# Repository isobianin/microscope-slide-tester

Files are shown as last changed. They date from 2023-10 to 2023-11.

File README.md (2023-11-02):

# Microscope slide tester

This is a small project done in collaboration with [Igor Kraev](https://uk.linkedin.com/in/igor-kraev-78a55821) from the Open University Microscope Suite. The device at hand is a simple continuity tester which is equipped with
a battery holder and can be recharged.

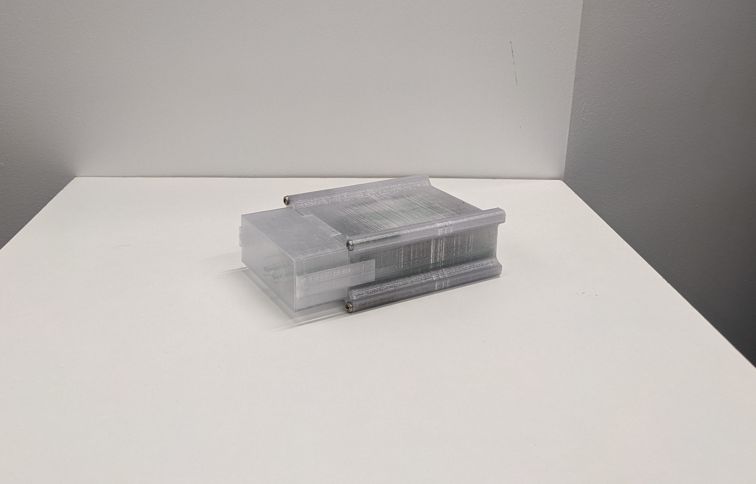
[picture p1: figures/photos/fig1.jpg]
 
 
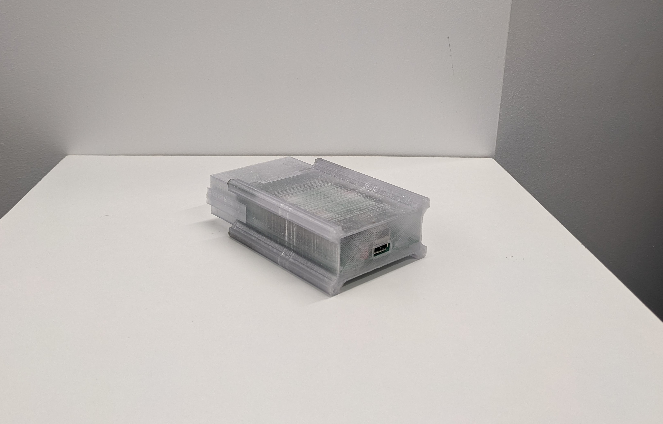
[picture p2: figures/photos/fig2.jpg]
 

The protocol of operation:

1. Take the electrode lid off.

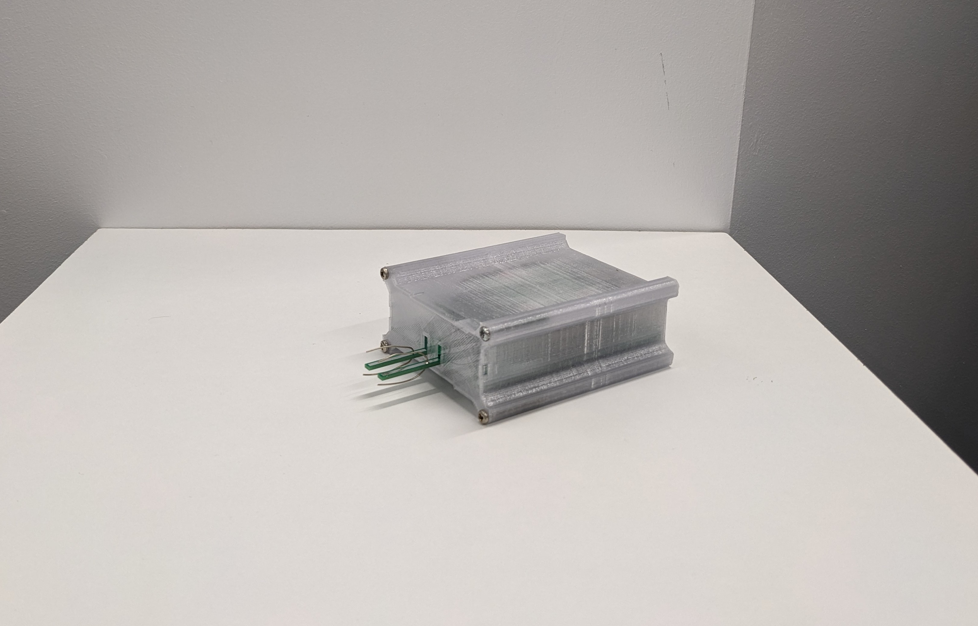
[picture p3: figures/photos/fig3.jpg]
lid-off
 

2. Clean your electrodes with either distilled water, acetone or IPA to remove any dust particles.

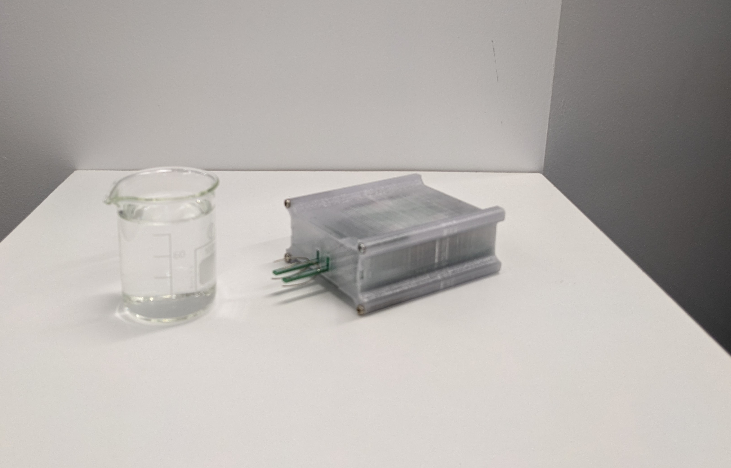
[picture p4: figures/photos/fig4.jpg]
solution
 

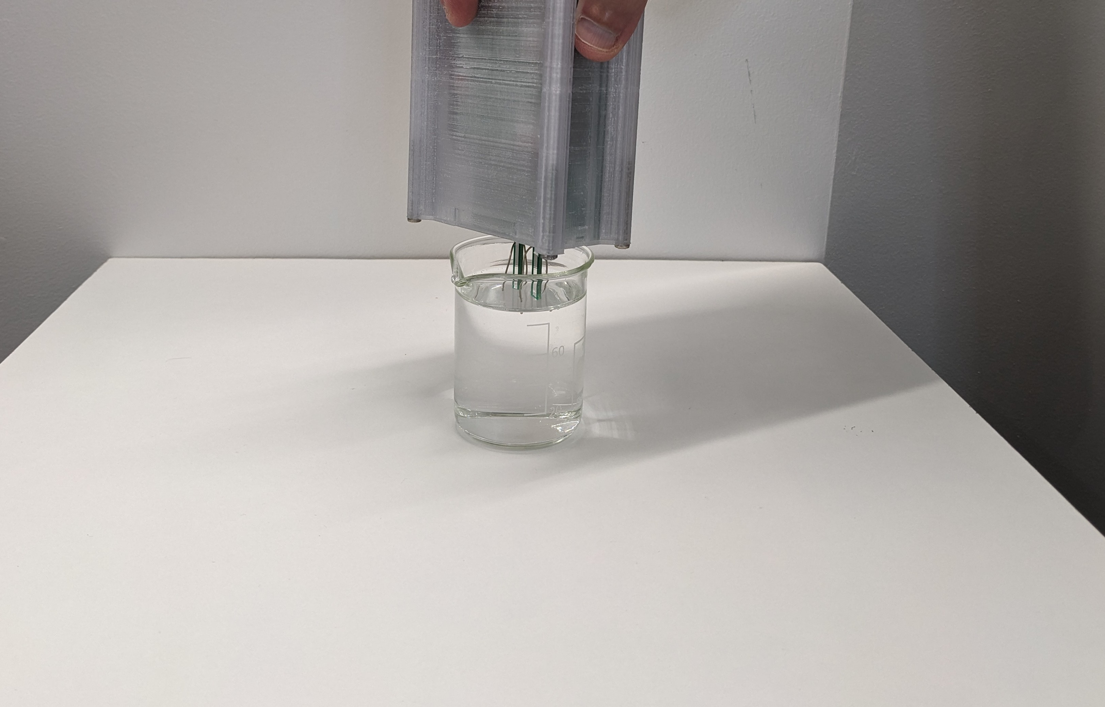
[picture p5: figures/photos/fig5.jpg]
cleaning
 

3. Press the slide against the electrodes. **If the front LED lights up, the side that is in contact with electrodes is conductive**.

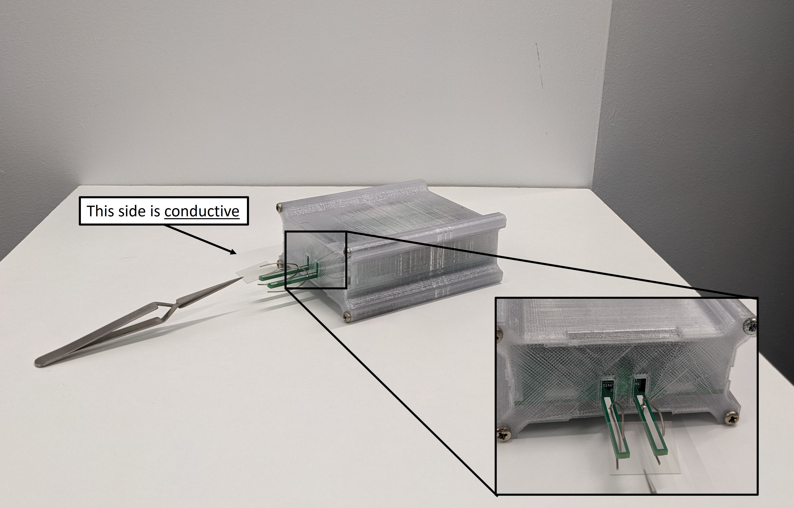
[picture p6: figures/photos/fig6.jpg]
non-conductive
 
 
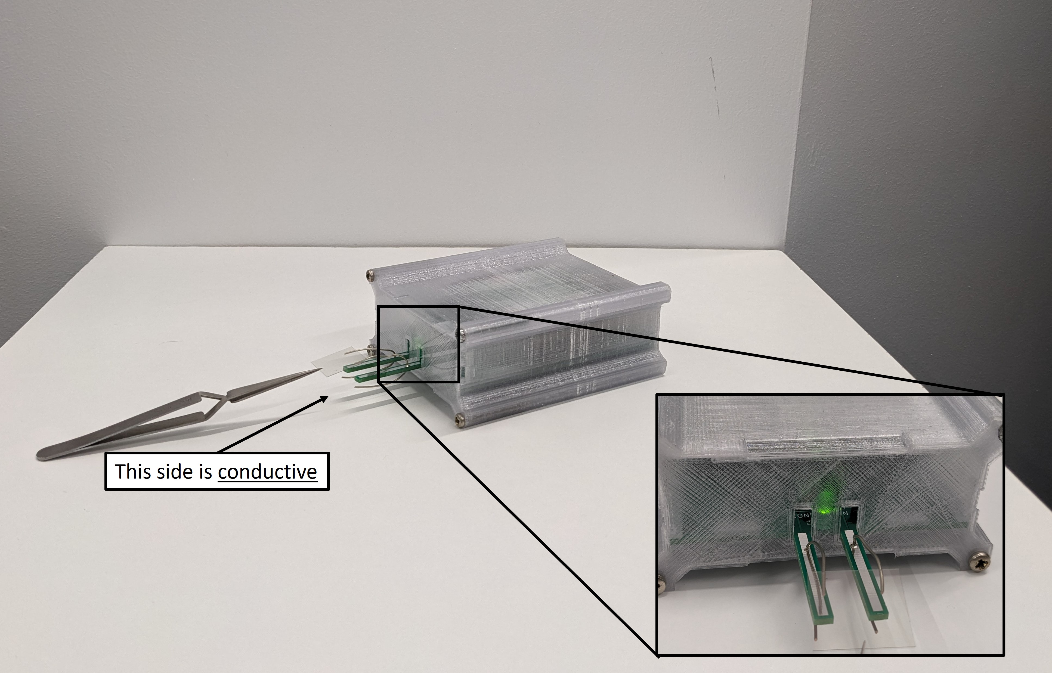
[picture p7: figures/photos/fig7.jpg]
conductive
 

4. Mark the conductive side.

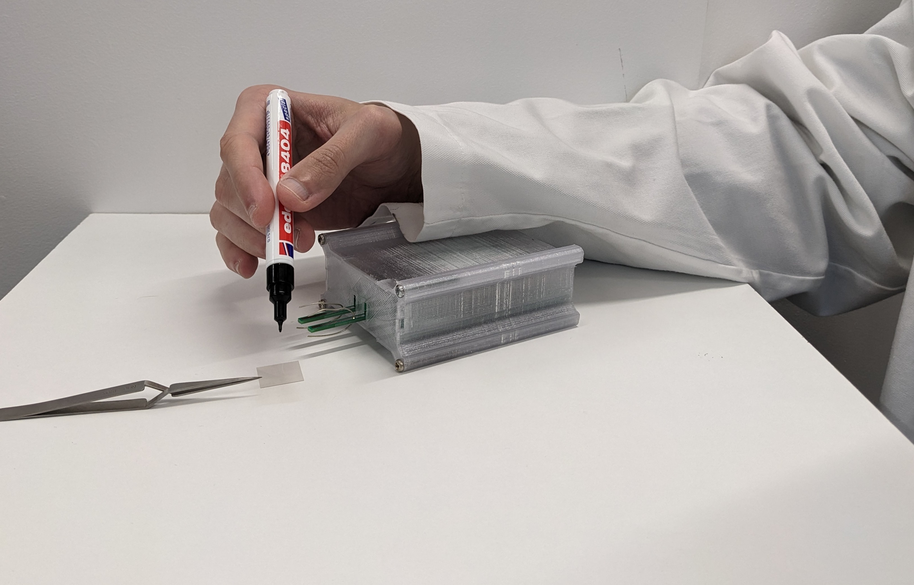
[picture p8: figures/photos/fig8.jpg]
marking
 

5. Repeat steps 1-4 for as many slides as needed.

6. When done, close the electrode lid.

 lid-on

The tester can be operated while being charged

# Recharging and safety

The tester can be recharged from any USB port (5V). That includes a PC, a laptop or even a phone charger. In the baseline version, USB B is installed at the back of the teste. It
can be swapped for any other convenient connector. USB A to USB B is a quite common cable and can be found in lots of printers, scanners, in electronic workshops, etc.

There are no specific regulations for the battery charging. When the tester is being charged, an indicator in the back lights up. A so-called **"trickle charge"** technique is used to 
charge the batteries. It means that the duration of charging is extremely long (tens of hours) but you cannot overcharge the batteries. 

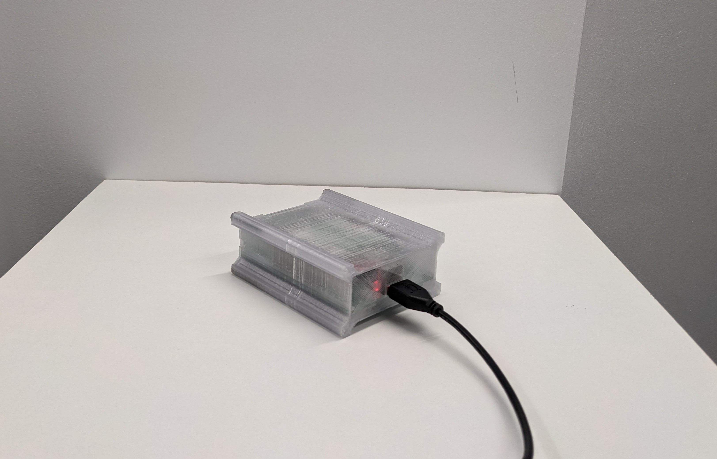
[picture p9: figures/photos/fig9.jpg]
recharging
 

A suggested protocol of recharging is to charge the device while you are at your workplace and avoid leaving it charging for days and days for safety measures.

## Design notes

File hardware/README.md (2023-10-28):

# Printed circuit boards

There are two available printed circuit board (PCB) designs. One features two plated through holes (PTH) which need to be soldered with a copper wire to create electrodes. This PCB is easier in manufacturing and handling.

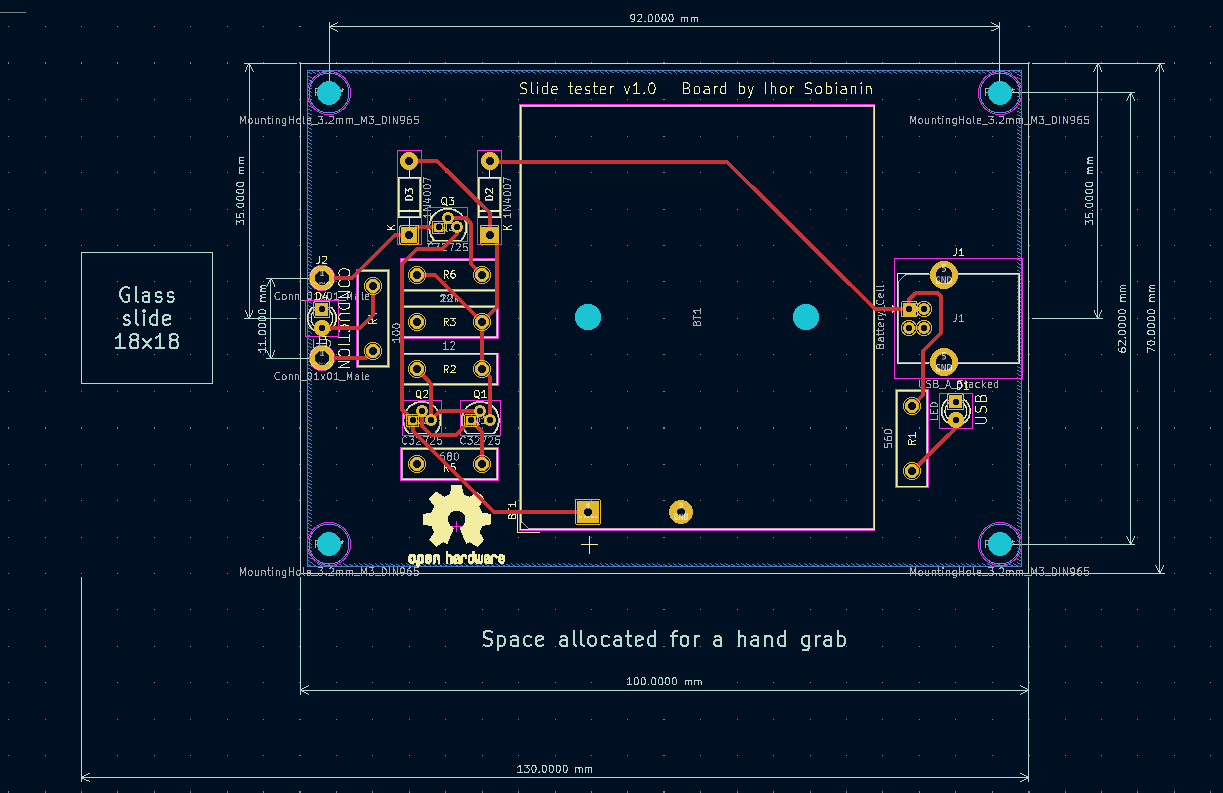
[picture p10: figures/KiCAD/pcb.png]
 

The other PCB design features two dedicated electrodes. The issue with this design, which is the original design, is that you need to explicitly specify to the manufacturer that these electrodes must cover
the whole area without any solder mask left on electrode pads. Otherwise, the solder mask is going to be taller than electrodes and a slide might not be able to touch the pads. Yet, this version also has PTH as a back-up.

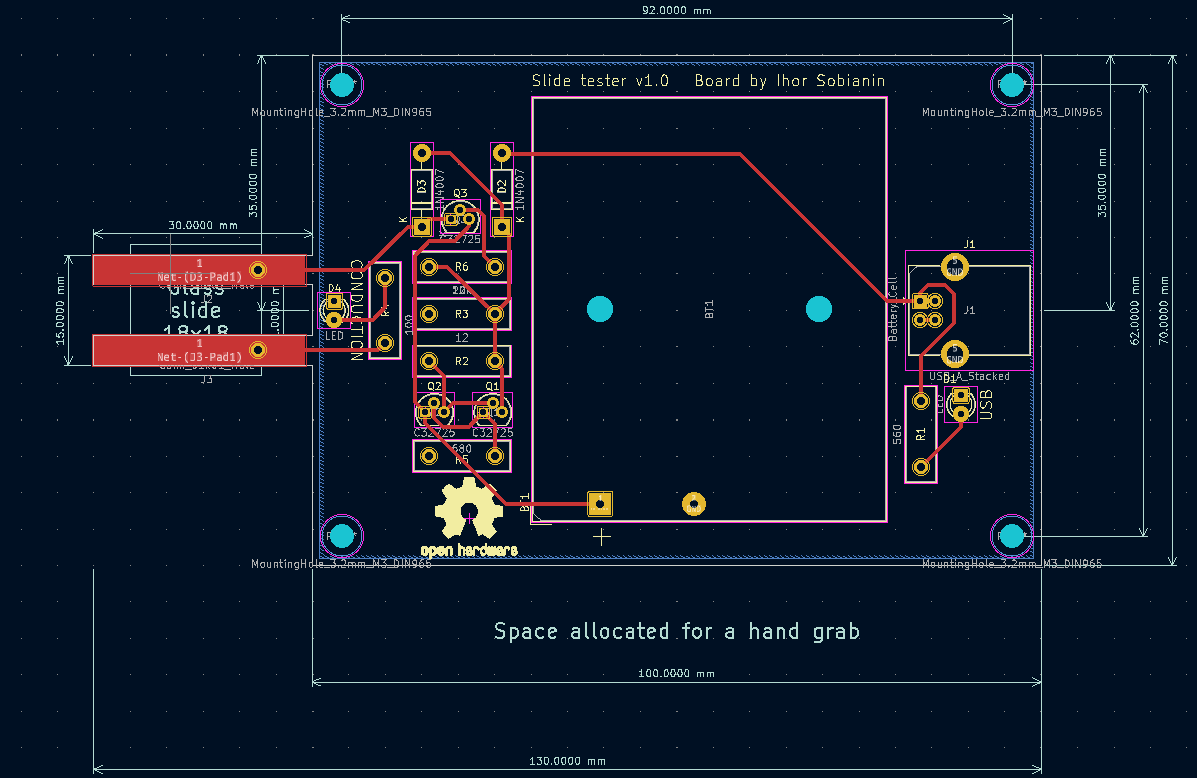
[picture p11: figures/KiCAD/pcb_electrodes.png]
 

Both use USB B connector for charging but feel free to swap those for whatever suits you.

# Bill of Materials

Components used:

Resistors

- 12 $\Omega$
- 100 $\Omega$
- 560 $\Omega$
- 680 $\Omega$
- 10k $\Omega$
- 22k $\Omega$

Diodes

- 2x 1n4007

LEDs

- 5 mm Green LED
- 5 mm Red LED

Transistors

- 3x C32725

Miscellaneous

- USB B connector
- 3x AA batteries
- 3x AA battery holder
- USB A to USB B cable

# Cicruitry

From the perpective of circuit design, the modus operandi is simple. When USB is connected, it set up the current mirror. Resistor R2 value is picked up to allow about 50 mA to pass through the Q2 transistor
into the batteries thus charging them. In the same time, Q3 acts as a switch and restricts current from flowing from the batteries while USB is connected and the tested D4 LED lights up using energy only from
the connector. When USB is disconnected, Q3 conducts and batteries are used to test slides.

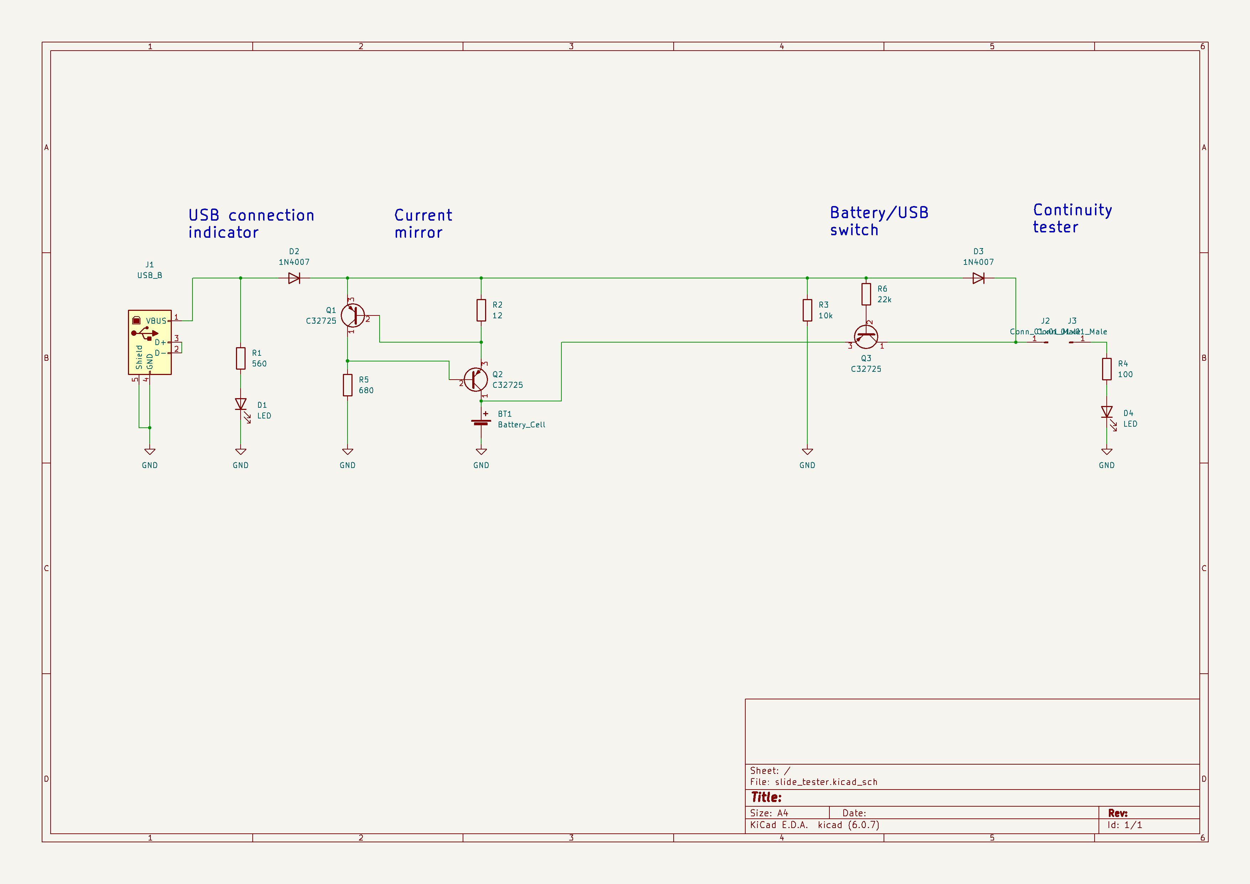
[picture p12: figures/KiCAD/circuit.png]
circuit
 

A highlight of this circuit is extensive use of C32725 transistors without use of any other components which makes it cheaper and more accessible.

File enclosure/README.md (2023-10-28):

# Enclosure

 The enclosure consists of 3 parts:
 
 1. base
 
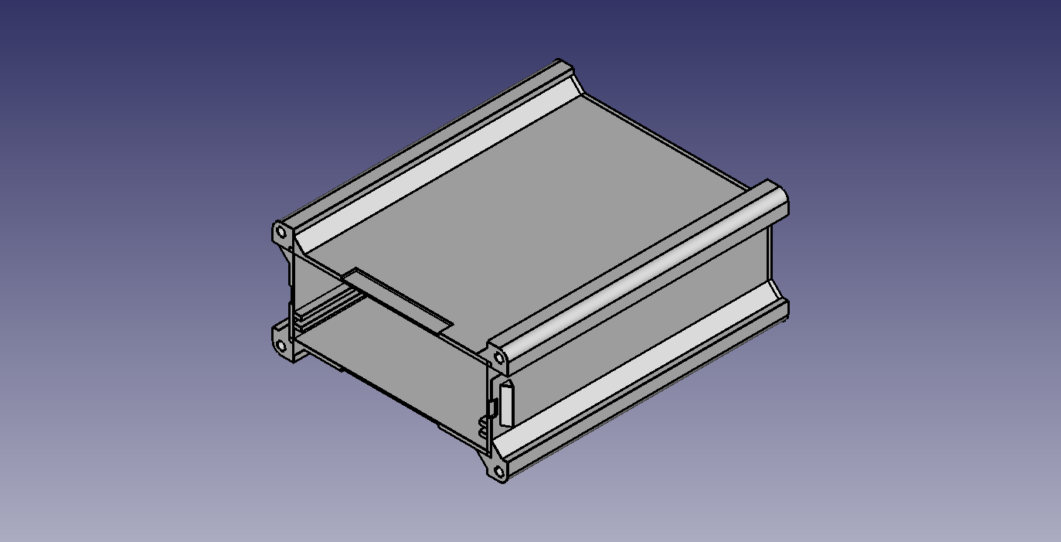
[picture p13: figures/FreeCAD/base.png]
base
 
 
 2. mechanical lid
 
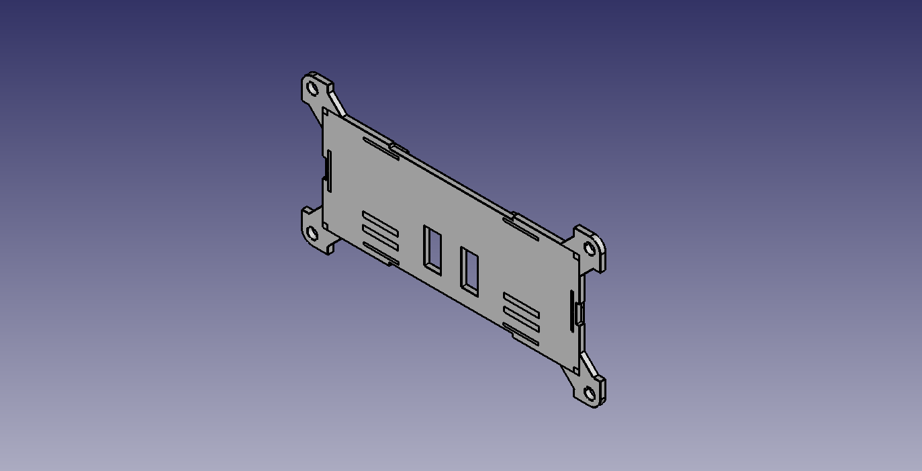
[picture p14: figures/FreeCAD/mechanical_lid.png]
mechanical lid
  
 
 3. electrode lid
 
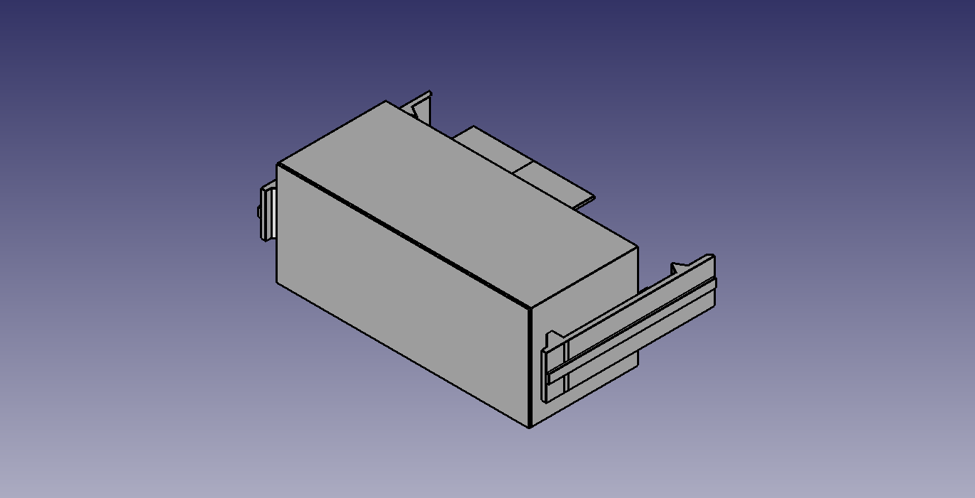
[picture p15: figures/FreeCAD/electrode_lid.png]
electrode lid
  
 
 They all can be 3D printed and barely require support material, if any. 
 
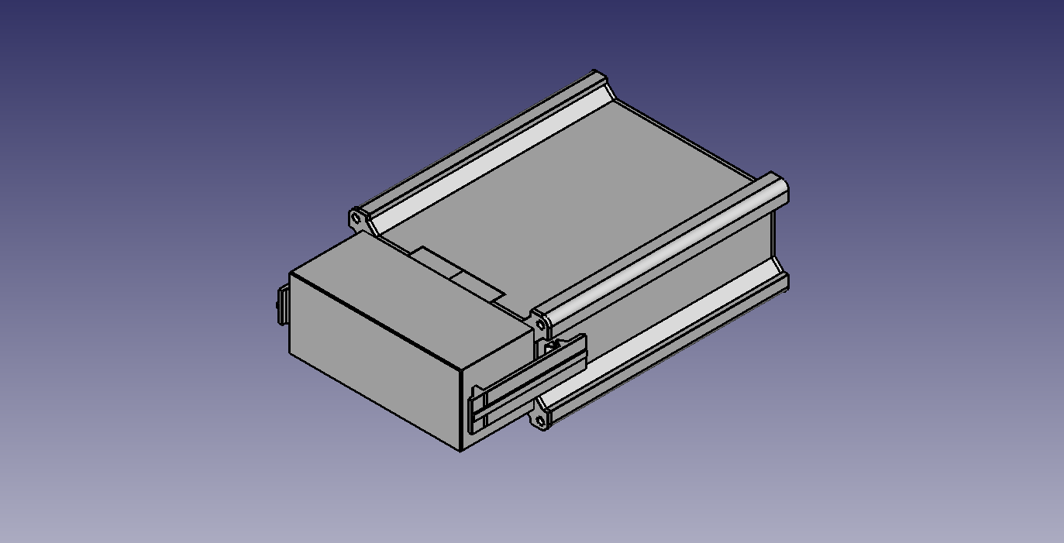
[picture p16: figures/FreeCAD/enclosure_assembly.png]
enclosure assembly
 
 
 # Parameters
 
 The FreeCAD file comes in a fully parametrised package. In the file you can find "Parameters" spreadsheet which contains almost all the desired geometrical dependencies.
 Thus, it is possible to customise the enclosure for your specific use. Moreover, it is relatively easy to limit the enclosure to the use of just two parts: the base and either one of lids.
 
 Most importantly, it is possible to vary the thickness and tolerances (both mechanical tolerances of the PCB and the 3D printer)
 
 # Fabrication
 
 Ultimaker S5 with UltraFuse transparent PET were used to fabricate the prototype. LEDs should still be visible even if the enclosure is printed with opaque filament. The front LED has enough space
 for it and the charging LED should still be visible through small gaps near the USB connector and the back of the enclosure.

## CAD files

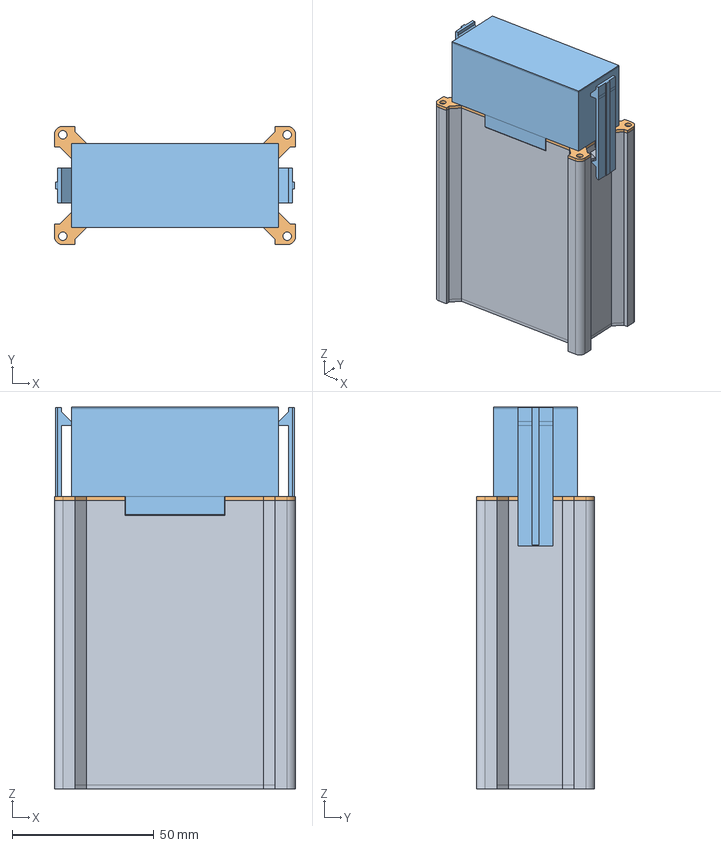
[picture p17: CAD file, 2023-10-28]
enclosure/uscope_slide_enclosure.FCStd
85.2 x 41.8 x 134.8 mm
EnclosureBase
MechanicalLid
ElectrodeLid

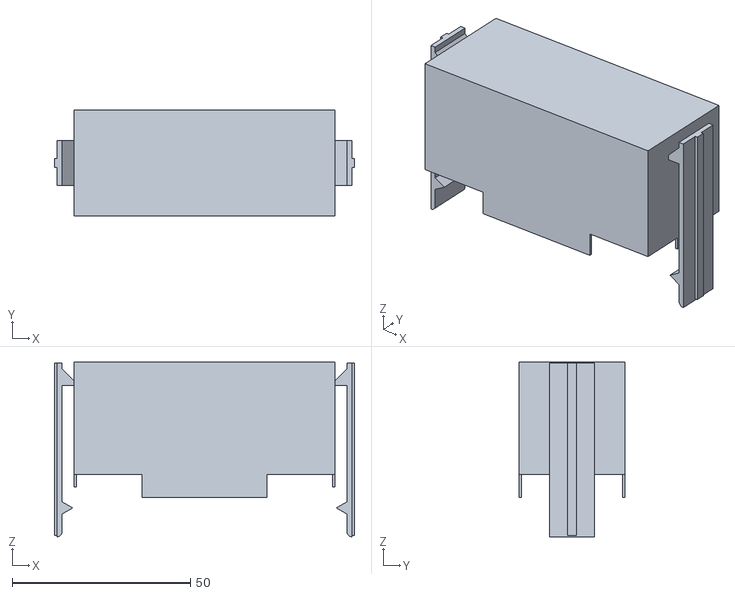
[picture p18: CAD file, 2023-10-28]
enclosure/uscope_slide_enclosure-ElectrodeLid.stl
84.2 x 29.8 x 49.1

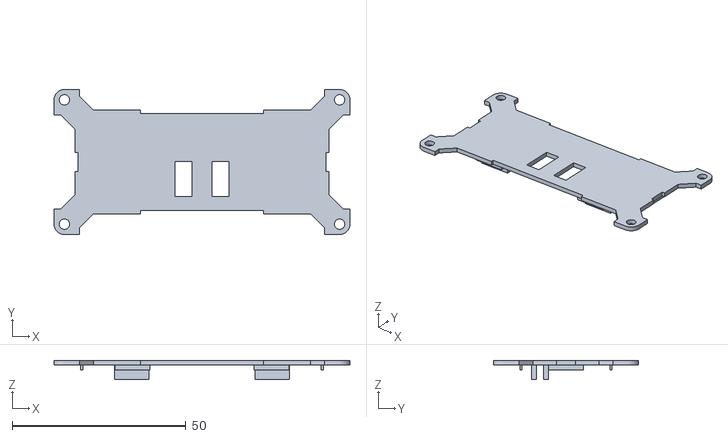
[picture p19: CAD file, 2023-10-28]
enclosure/uscope_slide_enclosure-MechanicalLid.stl
85.2 x 41.8 x 5.60

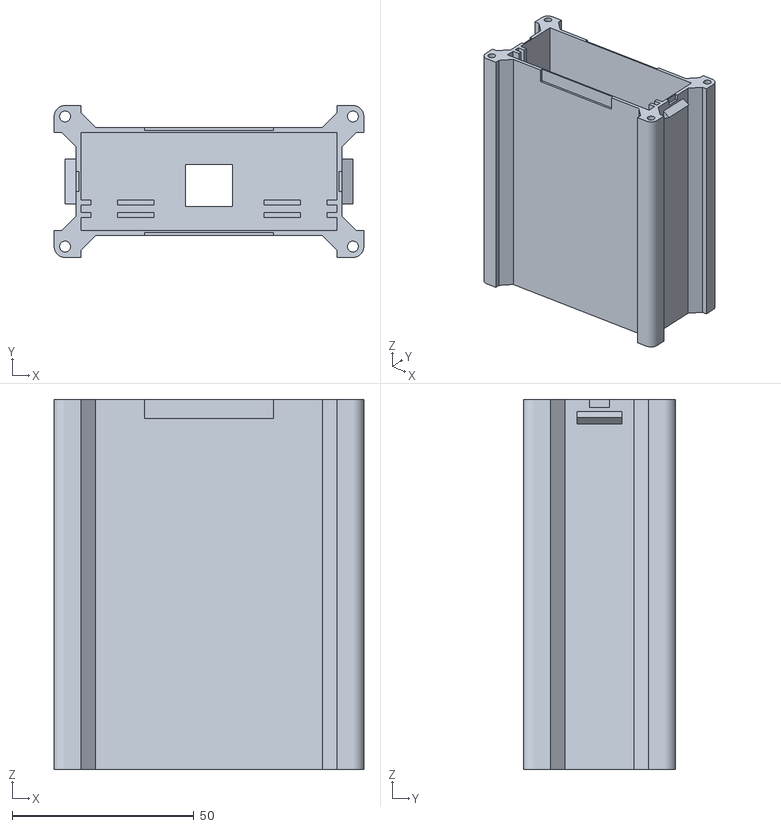
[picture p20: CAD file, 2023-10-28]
enclosure/uscope_slide_enclosure-EnclosureBase.stl
85.2 x 41.8 x 101.8

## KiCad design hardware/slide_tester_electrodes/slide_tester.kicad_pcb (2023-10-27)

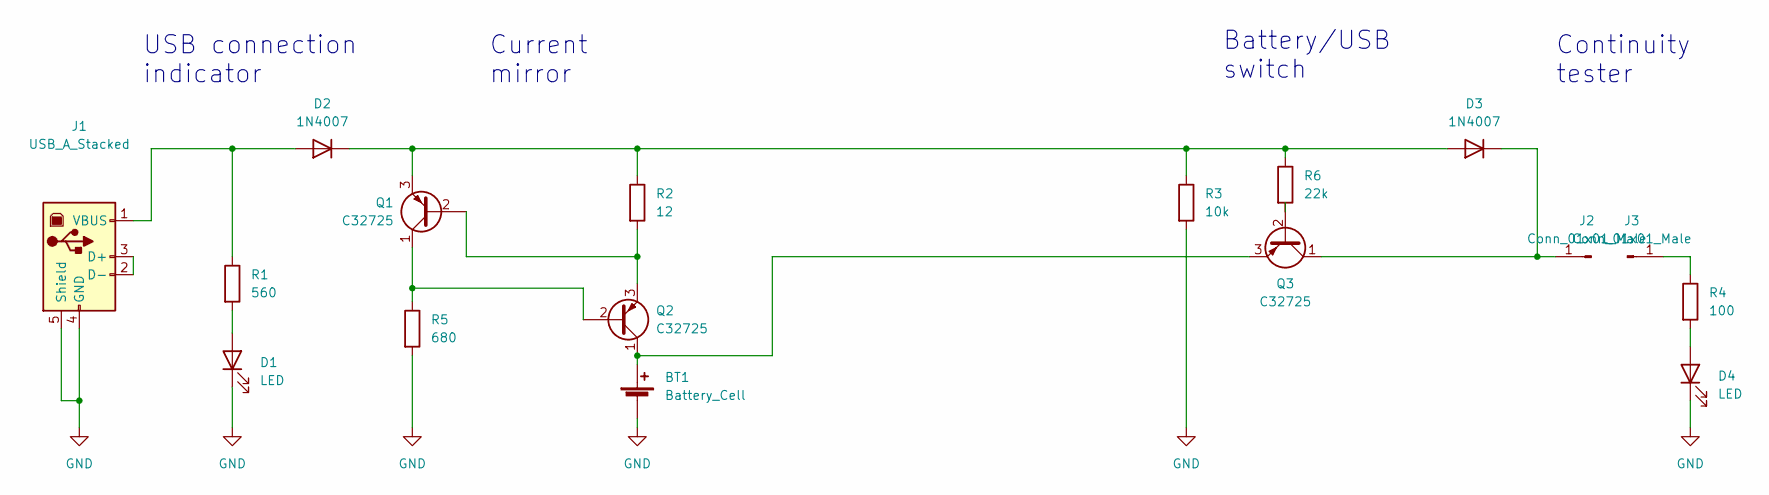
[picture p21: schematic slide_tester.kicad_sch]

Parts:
BT1: Battery_Cell; BatteryHolder_TruPower_BH-331P_3xAA
D1, D4: LED; LED_D3.0mm
D2, D3: 1N4007; D_DO-41_SOD81_P10.16mm_Horizontal
J1: USB_A_Stacked; USB_B_OST_USB-B1HSxx_Horizontal
J2, J3: Conn_01x01_Male; electrode_pad
Q1, Q2, Q3: C32725; TO-92
R1: 560; R_Box_L13.0mm_W4.0mm_P9.00mm
R2: 12; R_Box_L13.0mm_W4.0mm_P9.00mm
R3: 10k; R_Box_L13.0mm_W4.0mm_P9.00mm
R4: 100; R_Box_L13.0mm_W4.0mm_P9.00mm
R5: 680; R_Box_L13.0mm_W4.0mm_P9.00mm
R6: 22k; R_Box_L13.0mm_W4.0mm_P9.00mm

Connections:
GND: BT1.2 (-), D1.1 (K), D4.1 (K), J1.4 (GND), J1.5 (Shield), R3.2, R5.2
unnamed: BT1.1 (+), Q2.1 (C), Q3.3 (E)
unnamed: D1.2 (A), R1.2
unnamed: D2.1 (K), D3.2 (A), Q1.3 (E), R2.1, R3.1, R6.1
unnamed: D2.2 (A), J1.1 (VBUS), R1.1
unnamed: D3.1 (K), J2.1, Q3.1 (C)
unnamed: D4.2 (A), R4.2
unnamed: J1.2 (D-), J1.3 (D+)
unnamed: J3.1, R4.1
unnamed: Q1.1 (C), Q2.2 (B), R5.1
unnamed: Q1.2 (B), Q2.3 (E), R2.2
unnamed: Q3.2 (B), R6.2

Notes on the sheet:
Current mirror
Continuity tester
Battery/USB switch
USB connection indicator

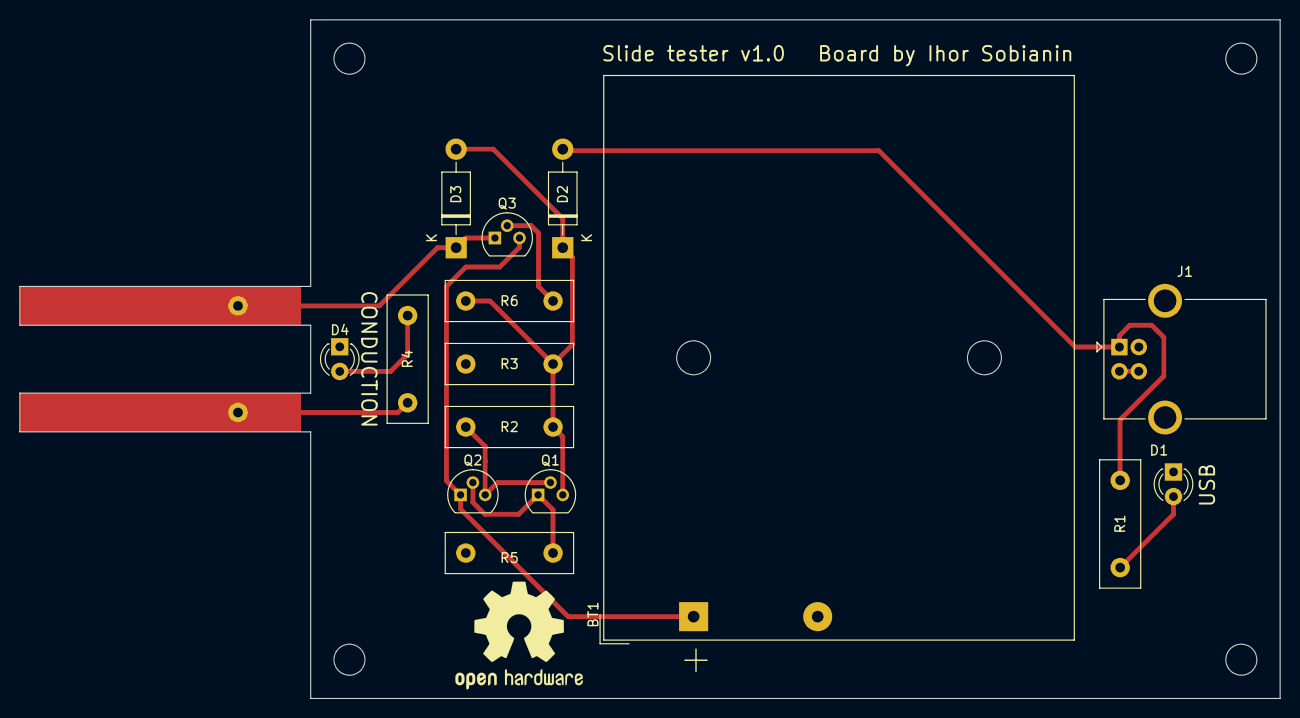
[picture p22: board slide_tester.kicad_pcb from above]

Board: 2 copper layers, 130.0 x 70.0 mm, 17 parts (0 on the bottom side), 12 nets.

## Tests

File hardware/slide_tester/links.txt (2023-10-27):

https://www.electroschematics.com/continuity-tester-differentiates-resistance/ - good design based on lm358
https://www.instructables.com/Modern-Continuity-Tester/
https://www.brighthubengineering.com/diy-electronics-devices/67224-build-yourself-a-simple-continuity-tester/

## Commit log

2023-10-27 Initial commit
    -create repo
    -add files
    [slide_tester-B_Cu.gbr, slide_tester-B_Mask.gbr, slide_tester-B_Paste.gbr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]
2023-10-27 Add enclosure
    Add FreeCAD enclosure files and STLs
    [uscope_slide_enclosure-ElectrodeLid.stl, uscope_slide_enclosure-EnclosureBase.stl, uscope_slide_enclosure-MechanicalLid.stl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]
2023-10-28 Add description, correct STL files
    Add readme-s
    Add figures
    Reorginise repo
    [slide_tester-B_Cu.gbr, slide_tester-B_Mask.gbr, slide_tester-B_Paste.gbr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]
2023-10-28 Add description, figures
    Add gitignore and delete back-ups
    [slide_tester.kicad_sch]
2023-10-28 Update FreeCAD files
    [uscope_slide_enclosure.FCStd]
